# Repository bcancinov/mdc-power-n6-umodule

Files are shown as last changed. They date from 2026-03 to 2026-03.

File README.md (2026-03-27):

# mdc-power-n6-umodule
Modular Detector Controller Power -6V uModule Mezzanine Module

## Overview
12V input to -6V output DC-DC module, 3A nominal output, used as one of the `mdc-power-*` bias rails.
Designed for 2 MHz sync operation.
Mezzanine module.

## Power Stage
- Controller: `LTM4651` (uModule)
  - Integrated µModule regulator including controller, MOSFETs, inductor, and support components.
  - EN55022B compliant regulator family (meets Class B EMI limits for conducted and radiated emissions).
  - External sync capability.

## Files
- Schematic: `power_n6_umodule.pdf`

## Board Dimensions
- 44.8 mm x 41.5 mm

## Board Stackup
- 4-layer PCB

## CAD
- Designed using KiCad 9.

## Interface
- Control pins: `EN` (enable) and `PG` / `~PGOOD` (power good).
- Connector: `LSHM-140-04.0-L-DV-A-N-K-TR` (Samtec LSHM series) mezzanine for power and control signals.
  - Common pinout is shared across the 16V, -16V, 6V, and 3.3V variants.
  - Unused output rails are tied to GND on the specific module variant.

## Images
Layout:
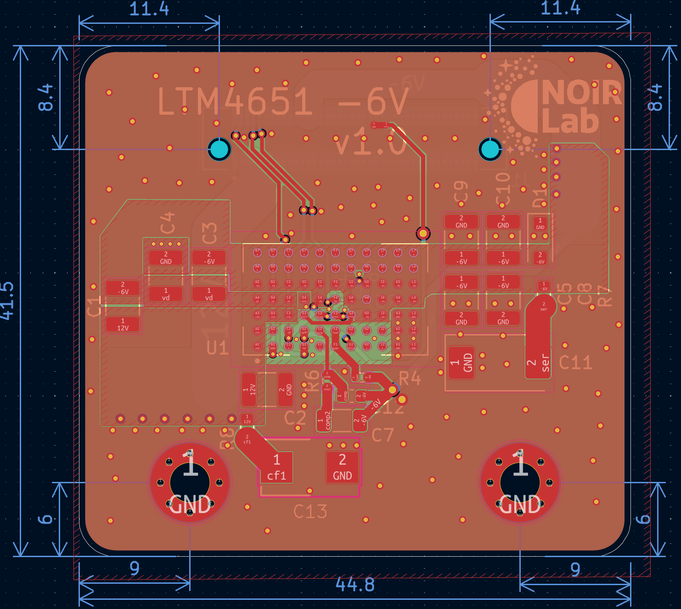
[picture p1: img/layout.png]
Layout


3D view:
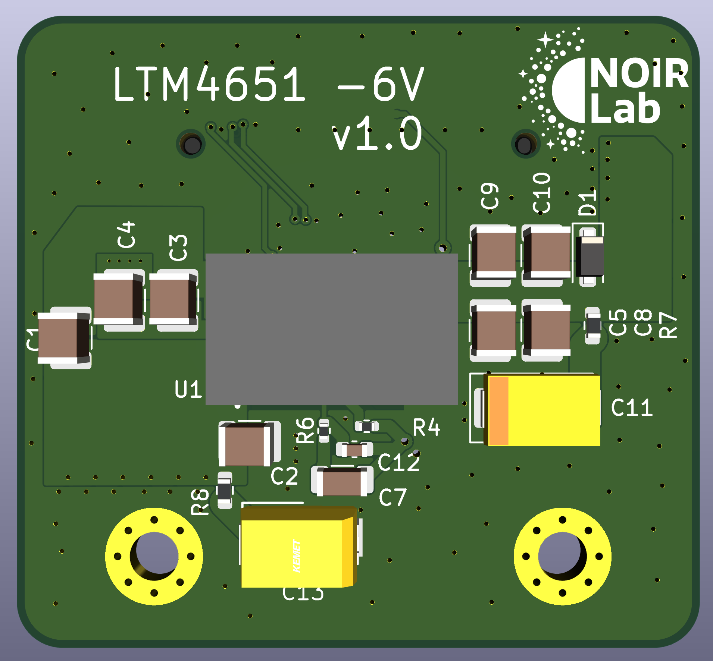
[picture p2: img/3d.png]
3D view


## License

This hardware design is licensed under the **Creative Commons Attribution-NonCommercial-ShareAlike 4.0 International License** (CC BY-NC-SA 4.0).

You are free to download, modify, and build upon this design for your own research or personal use, provided you give appropriate credit and share your modifications under the exact same license. **Commercial manufacturing or use of these designs is strictly prohibited without explicit permission.**

To view a copy of this license, visit [http://creativecommons.org/licenses/by-nc-sa/4.0/](http://creativecommons.org/licenses/by-nc-sa/4.0/) or see the `LICENSE` file in this repository.

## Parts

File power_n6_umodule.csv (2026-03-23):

Reference | Qty | MPN | M | Description
C1,C2,C3,C4 | 4 | GRM32ER71K475KE14L | Murata | 4.7 µF ±10% 80V Ceramic Capacitor X7R 1210 (3225 Metric)
C5,C8,C9,C10 | 4 | TMK325ABJ476MM-P | TAIYO YUDEN | 47 µF ±20% 25V Ceramic Capacitor X5R 1210 (3225 Metric)
C6 | 1 | GCM21BR71H105KA03L | Murata | 1 µF ±10% 50V Ceramic Capacitor X7R 0805 (2012 Metric)
C7 | 1 | GCM3195C1H333JA16D | Murata | 0.033 µF ±5% 50V Ceramic Capacitor C0G, NP0 1206 (3216 Metric)
C11 | 1 | T521V226M025ATE040 | KEMET | 22 µF Molded Tantalum Polymer Capacitor 25 V 2917 (7343 Metric) 40mOhm @ 100kHz
C12 | 1 | GCM1885C2A100FA16D | Murata | 10 pF ±1% 100V Ceramic Capacitor C0G, NP0 0603 (1608 Metric)
C13 | 1 | T521X107M025ATE060 | Kemet | 100 µF Molded Tantalum Polymer Capacitor 25 V 2917 (7343 Metric) 60mOhm @ 100kHz
D1 | 1 | CMMSH1-40L TR PBFREE | Central Semiconductor Corp | Diode 40 V 1A Surface Mount SOD-123F
H1,H2,NT1 | 3 |  |  | Mounting Hole with connection,Net tie, 2 pins
J1 | 1 | LSHM-140-04.0-L-DV-A-N-K-TR | Samtec | 80 Position Connector Self Mating, Non-Gendered, Hermaphroditic Surface Mount Gold
R1 | 1 | CRCW040262K0FKED | Vishay | 62 kOhms ±1% 0.063W, 1/16W Chip Resistor 0402 (1005 Metric) Automotive AEC-Q200 Thick Film
R2 | 1 | CRCW040244K2FKED | Vishay | 44.2 kOhms ±1% 0.063W, 1/16W Chip Resistor 0402 (1005 Metric) Automotive AEC-Q200 Thick Film
R3 | 1 | CRCW040224R9FKEDHP | Vishay | 24.9 Ohms ±1% 0.2W, 1/5W Chip Resistor 0402 (1005 Metric) Automotive AEC-Q200, Pulse Withstanding Thick Film
R4 | 1 | MCS04020C1203FE000 | Yageo | 120 kOhms ±1% 0.063W, 1/16W Chip Resistor 0402 (1005 Metric) Anti-Sulfur Thin Film
R6 | 1 | CRCW04024K75FKED | Vishay | 4.75 kOhms ±1% 0.063W, 1/16W Chip Resistor 0402 (1005 Metric) Automotive AEC-Q200 Thick Film
R7,R8 | 2 | RCWE0603R500FKEA | Vishay | 500 mOhms ±1% 0.2W, 1/5W Chip Resistor 0603 (1608 Metric) Automotive AEC-Q200, Current Sense, Moisture Resistant Thick Film
U1 | 1 | LTM4651EY#PBF | Analog Devices | Non-Isolated PoL Module DC DC Converter 1 Output -0.5 ~ -26.5V 3.6V - 58V Input

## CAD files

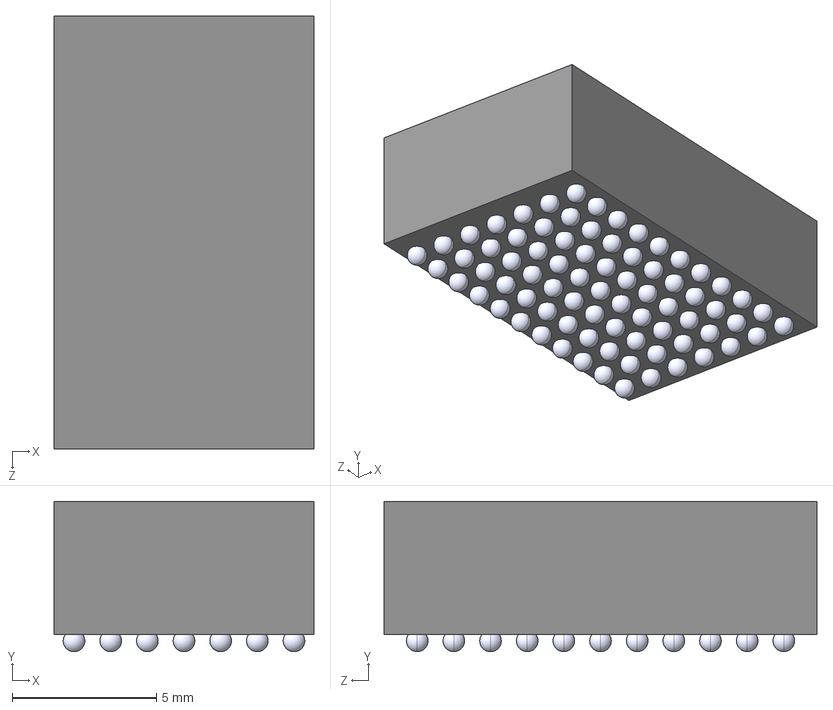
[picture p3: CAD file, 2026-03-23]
step/LTM4651EY_PBF.step
9.00 x 5.21 x 15.0 mm

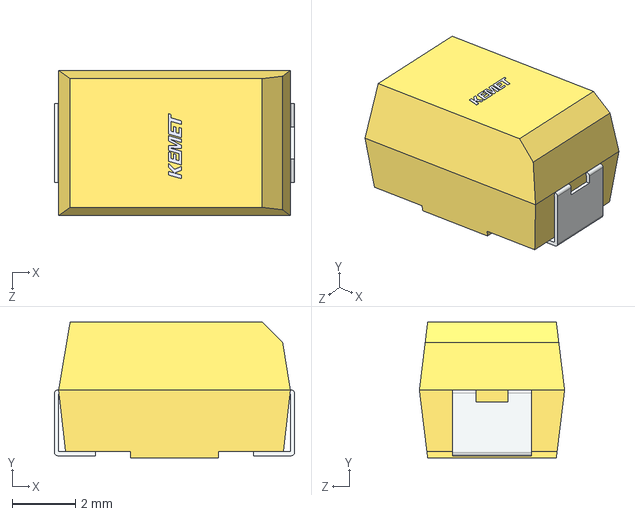
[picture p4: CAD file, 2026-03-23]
step/T521X.step
7.60 x 4.30 x 4.60 mm

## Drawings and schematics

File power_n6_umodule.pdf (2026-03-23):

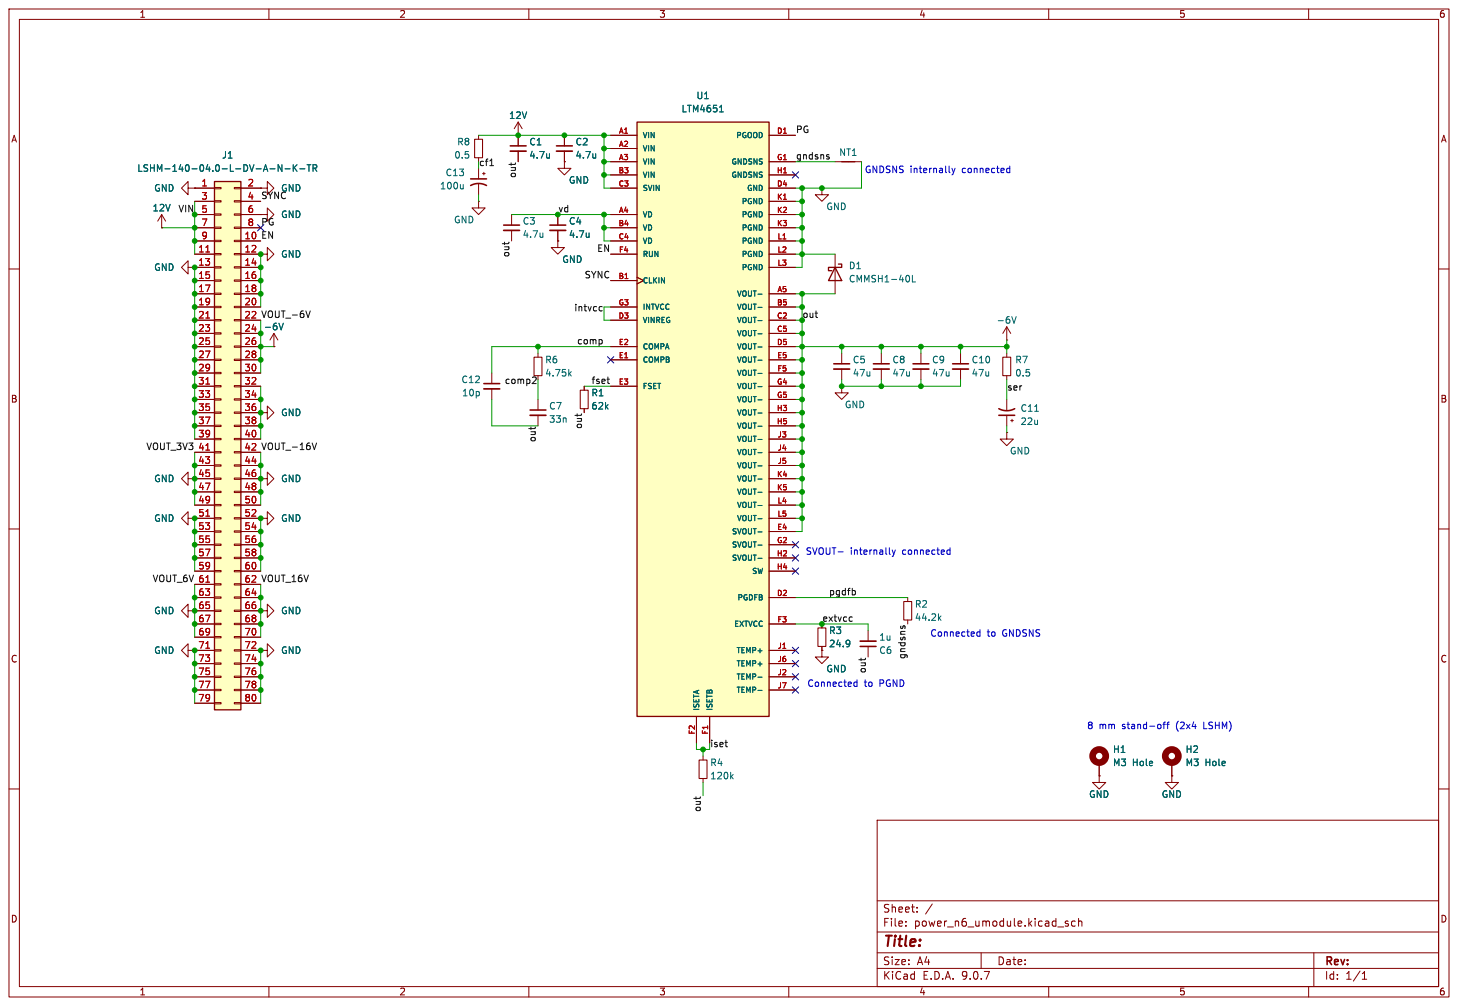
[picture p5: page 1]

LSHM-140-04.0-L-DV-A-N-K-TR GND GND GND

Id: 1/1 Title: File: power_n6_umodule.kicad_sch Sheet: /

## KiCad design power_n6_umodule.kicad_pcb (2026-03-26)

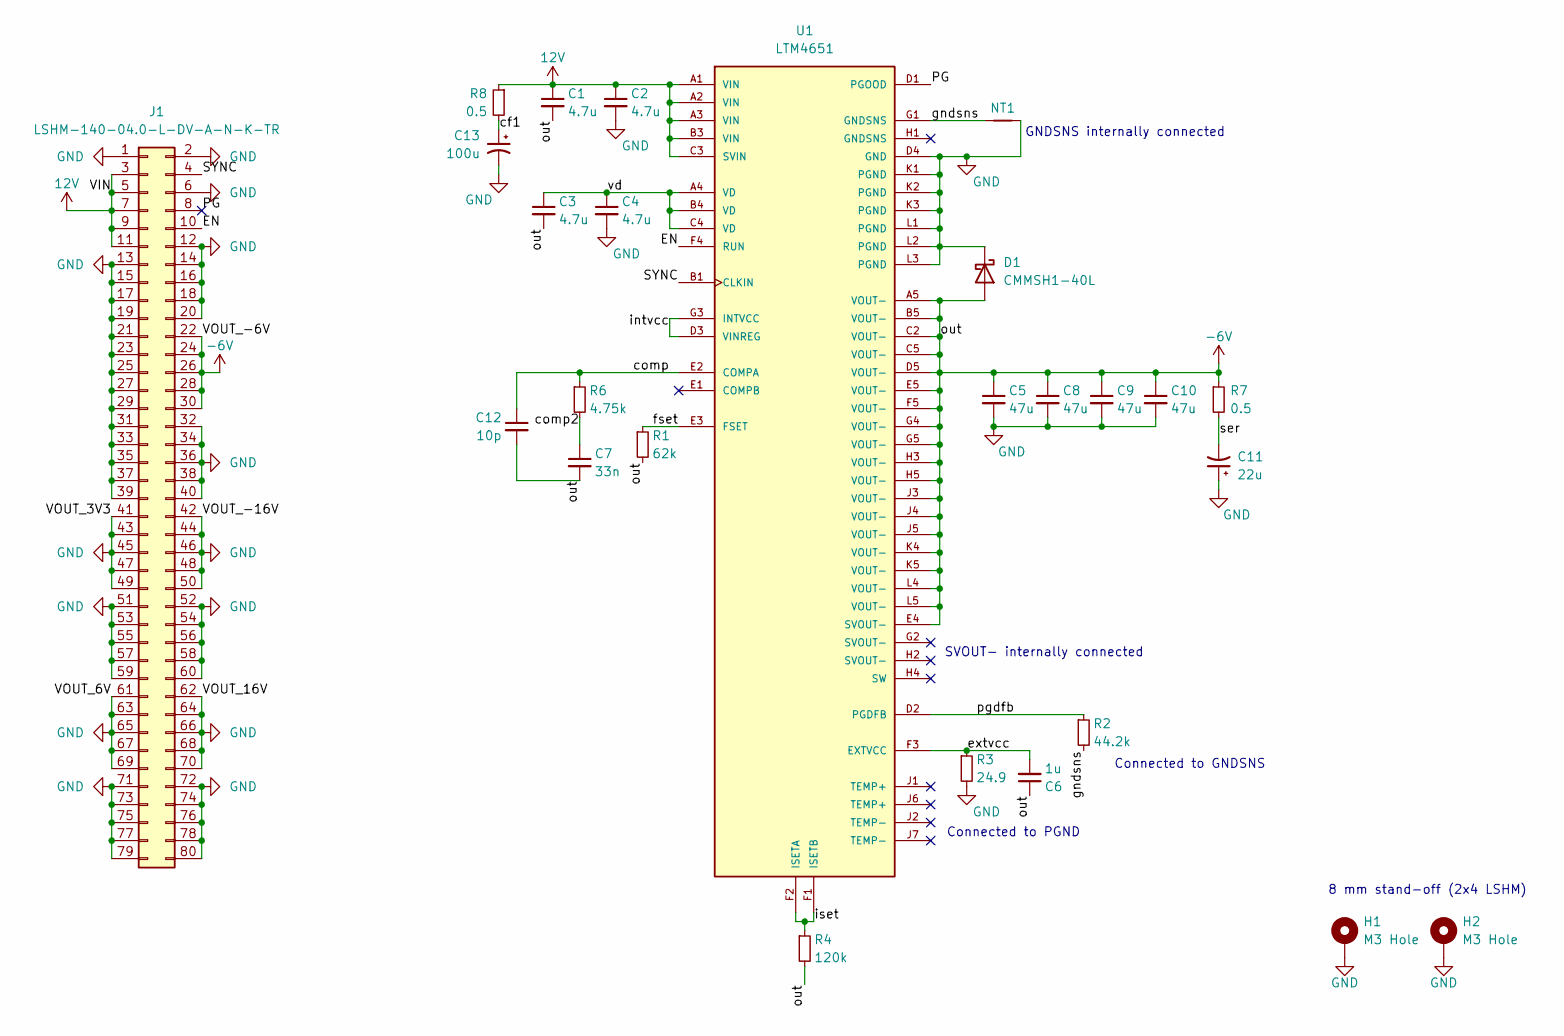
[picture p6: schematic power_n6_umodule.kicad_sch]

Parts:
C1, C2, C3, C4: 4.7u; C_1210_3225Metric; MPN GRM32ER71K475KE14L
C5, C8, C9, C10: 47u; C_1210_3225Metric; MPN TMK325ABJ476MM-P
C6: 1u; C_0805_2012Metric; MPN GCM21BR71H105KA03L
C7: 33n; C_1206_3216Metric; MPN GCM3195C1H333JA16D
C11: 22u; CP_EIA-7343-20_Kemet-V; MPN T521V226M025ATE040
C12: 10p; C_0603_1608Metric; MPN GCM1885C2A100FA16D
C13: 100u; T521X; MPN T521X107M025ATE060
D1: CMMSH1-40L; D_SOD-123F; MPN CMMSH1-40L TR PBFREE
H1, H2: M3 Hole; MountingHole_3.2mm_M3_Pad_Via
J1: LSHM-140-04.0-L-DV-A-N-K-TR; SAMTEC_LSHM-140-04.0-L-DV-A-N-K-TR; MPN LSHM-140-04.0-L-DV-A-N-K-TR
NT1: NetTie-2_SMD_Pad0.5mm
R1: 62k; R_0402_1005Metric; MPN CRCW040262K0FKED
R2: 44.2k; R_0402_1005Metric; MPN CRCW040244K2FKED
R3: 24.9; R_0402_1005Metric; MPN CRCW040224R9FKEDHP
R4: 120k; R_0402_1005Metric; MPN MCS04020C1203FE000
R6: 4.75k; R_0402_1005Metric; MPN CRCW04024K75FKED
R7, R8: 0.5; R_0603_1608Metric; MPN RCWE0603R500FKEA
U1: LTM4651; MPN LTM4651EY#PBF

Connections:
12V: C1.1, C2.1, J1.3, J1.5, J1.7, J1.9, J1.11, R8.1, U1.A1 (VIN), U1.A2 (VIN), U1.A3 (VIN), U1.B3 (VIN), U1.C3 (SVIN)
-6V: C1.2, C3.2, C5.1, C6.1, C7.2, C8.1, C9.1, C10.1, C12.2, D1.2 (A), J1.22, J1.24, J1.26, J1.28, J1.30, R1.2, R4.2, R7.1, U1.A5 (VOUT-), U1.B5 (VOUT-), U1.C2 (VOUT-), U1.C5 (VOUT-), U1.D5 (VOUT-), U1.E4 (SVOUT-), U1.E5 (VOUT-), U1.F5 (VOUT-), U1.G4 (VOUT-), U1.G5 (VOUT-), U1.H3 (VOUT-), U1.H5 (VOUT-), U1.J3 (VOUT-), U1.J4 (VOUT-), U1.J5 (VOUT-), U1.K4 (VOUT-), U1.K5 (VOUT-), U1.L4 (VOUT-), U1.L5 (VOUT-)
/EN: J1.10, U1.F4 (RUN)
/PG: J1.8, U1.D1 (PGOOD)
/SYNC: J1.4, U1.B1 (CLKIN)
/cf1: C13.1, R8.2
/comp: C12.1, R6.1, U1.E2 (COMPA)
/comp2: C7.1, R6.2
/extvcc: C6.2, R3.1, U1.F3 (EXTVCC)
/fset: R1.1, U1.E3 (FSET)
/gndsns: NT1.1, R2.2, U1.G1 (GNDSNS)
/intvcc: U1.D3 (VINREG), U1.G3 (INTVCC)
/iset: R4.1, U1.F1 (ISETB), U1.F2 (ISETA)
/pgdfb: R2.1, U1.D2 (PGDFB)
/ser: C11.2, R7.2
/vd: C3.1, C4.1, U1.A4 (VD), U1.B4 (VD), U1.C4 (VD)
GND: C2.2, C4.2, C5.2, C8.2, C9.2, C10.2, C11.1, C13.2, D1.1 (K), H1.1, H2.1, J1.1, J1.2, J1.6, J1.12, J1.13, J1.14, J1.15, J1.16, J1.17, J1.18, J1.19, J1.20, J1.21, J1.23, J1.25, J1.27, J1.29, J1.31, J1.32, J1.33, J1.34, J1.35, J1.36, J1.37, J1.38, J1.39, J1.40, J1.41, J1.42, J1.43, J1.44, J1.45, J1.46, J1.47, J1.48, J1.49, J1.50, J1.51, J1.52, J1.53, J1.54, J1.55, J1.56, J1.57, J1.58, J1.59, J1.60, J1.61, J1.62, J1.63, J1.64, J1.65, J1.66, J1.67, J1.68, J1.69, J1.70, J1.71, J1.72, J1.73, J1.74, J1.75, J1.76, J1.77, J1.78, J1.79, J1.80, NT1.2, R3.2, U1.D4 (GND), U1.K1 (PGND), U1.K2 (PGND), U1.K3 (PGND), U1.L1 (PGND), U1.L2 (PGND), U1.L3 (PGND)

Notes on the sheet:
SVOUT- internally connected
8 mm stand-off (2x4 LSHM)
Connected to GNDSNS
GNDSNS internally connected
Connected to PGND

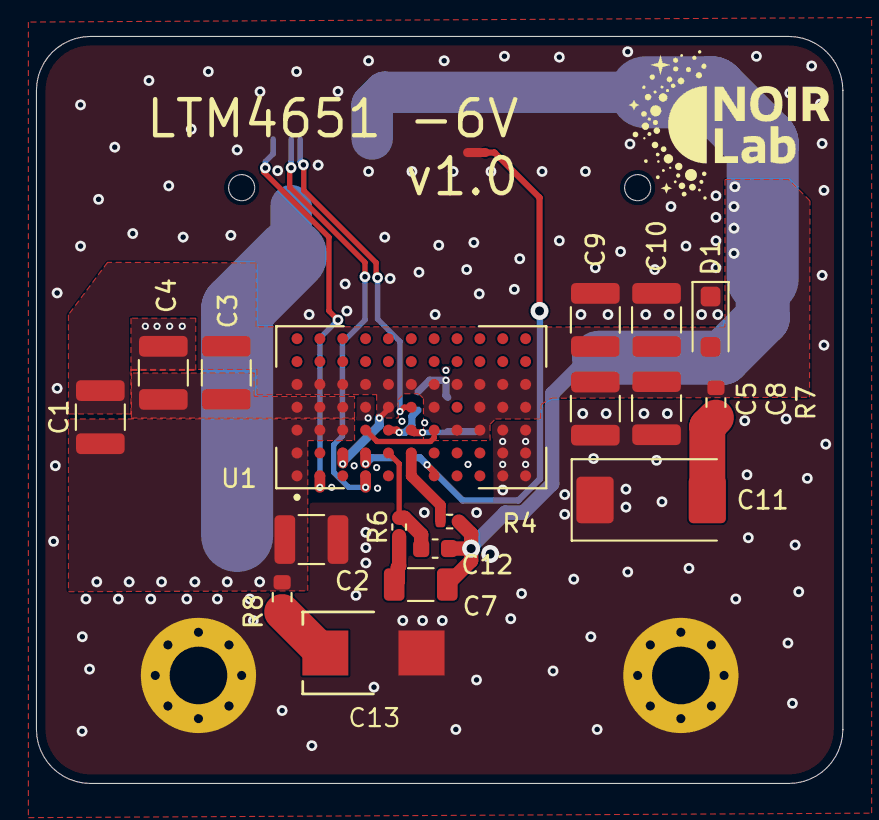
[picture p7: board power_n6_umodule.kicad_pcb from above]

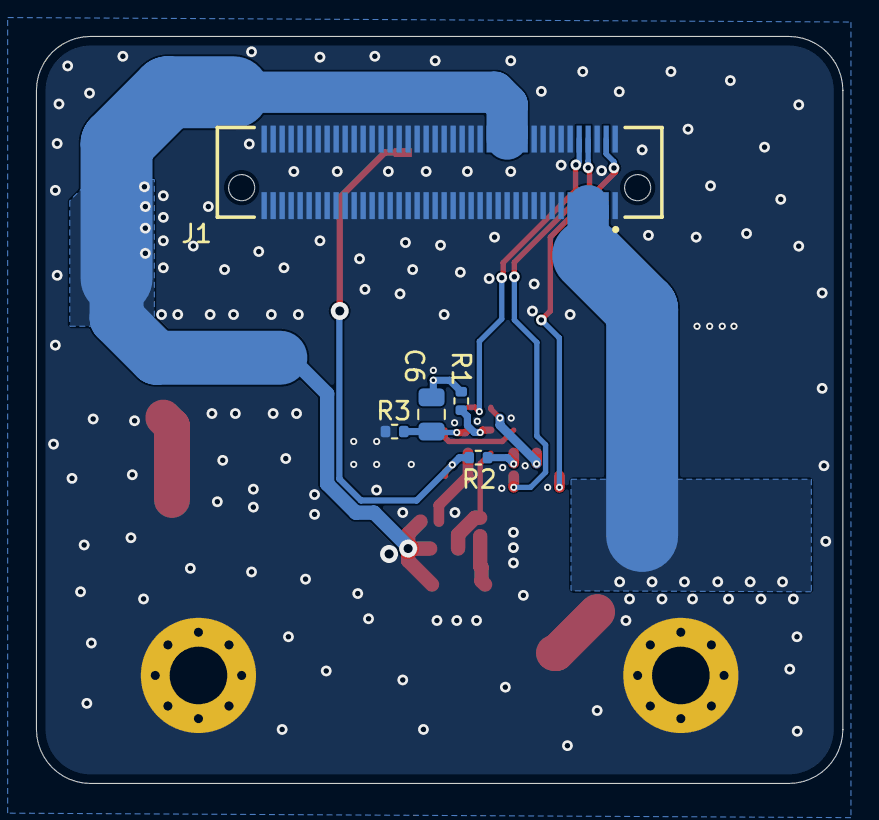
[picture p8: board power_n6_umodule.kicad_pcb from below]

Board: 4 copper layers, 44.8 x 41.5 mm, 26 parts (5 on the bottom side), 17 nets.
